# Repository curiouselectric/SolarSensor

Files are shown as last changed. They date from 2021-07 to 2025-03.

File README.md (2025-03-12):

# Solar Sensor
A DIY solar irradiance sensor.

Here are the design files (hardware, PCB and firmware) for a relatively low cost solar irradaince sneesor (called a pyranometer).

[Information relating to the design choices for this unit is available in a blog post here](https://www.re-innovation.co.uk/docs/low-cost-diy-solar-irradiance-sensor-for-pv-system-monitoring/).

This pyranometer is design to measure solar irradiance in Watts per meter squared. This is useful for monitoring systems for solar photovoltaic panels. It can also be used as an indicator value for light levels in many systems.

The main things to note with this design are:

* It does not apply any corrections/filtes for human eye parameters (whcih Lux sensors use, typically for photography or dimming algorithms)
* It does not apply any corrections/filters for plant growing characteristics (typically called PAR  - [Photosynthetically active radiation](https://en.wikipedia.org/wiki/Photosynthetically_active_radiation)

The main issue with this design is the calibration of the sensor data to its actual real-world data. I have attempted to give sensible conversion factors for the sensors used, but calibration for each exact set up with 
calibrated measurement equipment is potentially needed, depending upon you application.

If you are looking for relative changes in irradiance then this sensor is perfectly suitable. 

# Overview
This unit reads irradiance from a photo diode sensor (like a P-N junction in a typical solar photovoltaic cell) every 100mS or so. 

The sensor uses an accurate 16 bit Analog to Digital converter (ADC) (rather than the 10 bit resolution on-board the micrcontorller). This allows for much finer montitoring of the very small current from the solar sensor. As the sensor will 'max out' well below typicaly outdoor irradiance levels, then we use a 6mm PTFE diffuse to attenuate the irradiance signal. This was caclualted from trial and error, but allows up to 2000W/m² to be measured.

There is also a temperature sensor on-board to adjust readings for the sensor temperature. 

It averages those values over different sampling periods of 1, 10, 60 (1 min), 600 (10 min), 3600 (1 hour) seconds. It has an ATMega328 microcontroller onboard for measuring the sensors, processing commands and returnign serial data. A simple serial interface has been implemented (at max 57600 baud) to service requests from another device (such as a data logger or monitoring system). The serial requests can also have CRC for error checking.

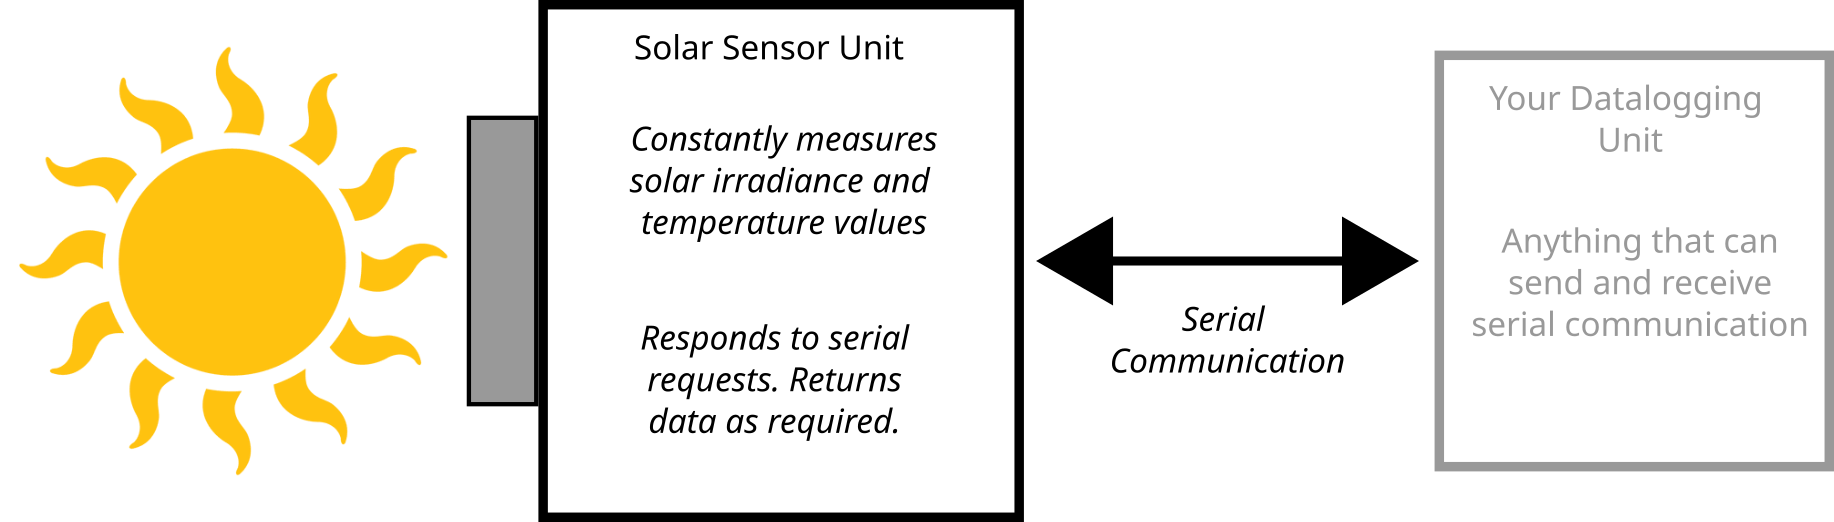
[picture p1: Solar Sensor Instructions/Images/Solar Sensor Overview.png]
Overview


I originally designed this to interface to an ESP32 data logger, which sleeps most of the time. The ESP32 wakes up, gets the data it needs, then goes back to sleep, knowing the solar sensor is always monitoring.

It was designed as a relatively simple interface to remove the need for monitoring irradiance data and averaging it. 
There are other dvices in this range, [including a wind sensor](https://www.curiouselectric.co.uk/collections/environment/products/wind-sensor-interface).

## Irradiance Measurements

The unit stores average irradiance values from the sensor for 1 second, 10 second, 1 min, 10 min and 1 hour values. It also records the maximum and minimum irradiance.

The unit converts the tiny current from the solar PV cell within a photodiode into a "Watts per meter squared" value using a y=mx+c linear conversion, where y is the irradiance value and x is the ADC reading from the photo diode sensor circuitry. m and c are stored in EEPROM and have default values of m=1 and c=0. These are floats and can be changed as required through the serial interface. Any updated values are stored in EEPROM. The output will not go negative - it will round out at 0.

The photodiode used within the prototype is the [SFH203 from OSRAM](https://look.ams-osram.com/m/67e1a90044b03ee9/original/SFH-203.pdf). This has an output repsonse between 400-1100nm with a sensitive area of 1mm² giving a whopping 80uA of photocurrent!

## Temperature Measurements

Temperature near to the board inside the unit is measured using a surface mounted LM75 I2C temperature sensor. This will give an approximate temperature of the sensor. This sensor is accurate to 0.5C. 
Temperature compensation can be applied by updating the config file within the fireware. If the "APPLY_TEMP_COMP" flag is set to "true" then the "TEMP_COMP_VAL" is applied at the real temperature compare to the "RATED_TEMP". Typically the rated temperature is 25C and comes from the [data sheet](https://look.ams-osram.com/m/67e1a90044b03ee9/original/SFH-203.pdf). For the SFH203 the "TEMP_COMP_VAL" is 0.18 %/K and the "RATED_TEMP" is 25C

So an example would be measuring 500 W/m² but the temperature sensor reads 50C.
The rated temperature is 25C, so we need to apply a compensation of (50 - 25) * 0.18 % = 4.5%, so the sensor will be reading 4.5% under the real value (as output is inversly affected by temperature), So the actual irradiance is 500 + (500*0.045) = 522.5 W/m². Not a huge difference, but this might be important.

You can also remove the temperature compensation and record the irradiance and temperature seperately and apply the compensation later.

# Operation

There are two mode of operation, depending upon your use case:

## Response Mode

In this mode then the unit responds to serial requests made. You ask the sensor for data and this is returned. It never sends anything unless asked. 
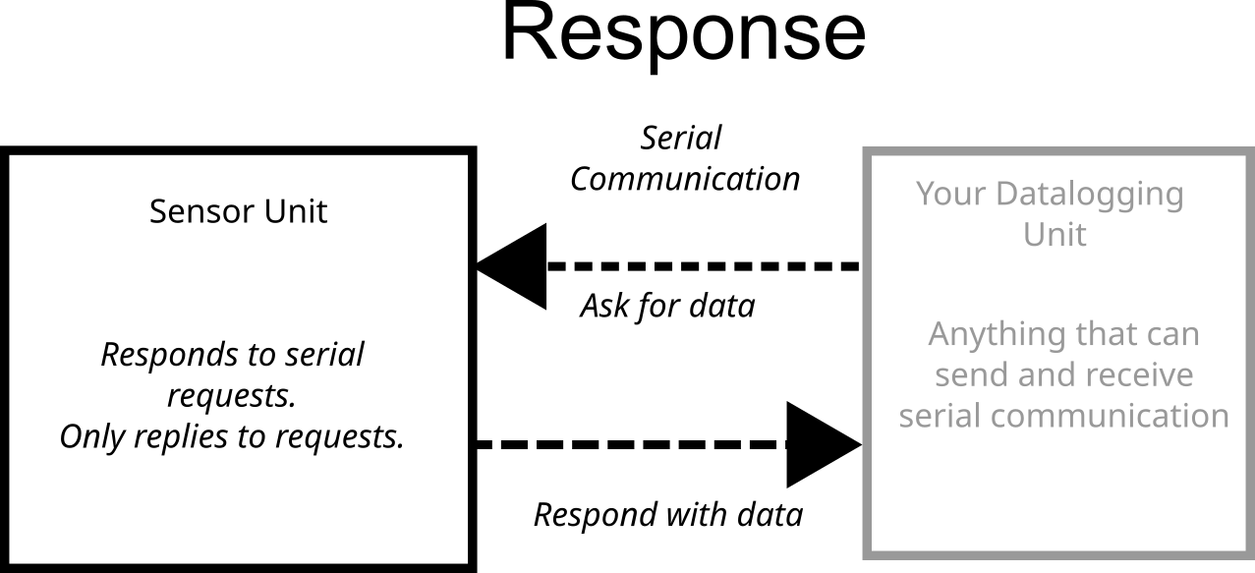
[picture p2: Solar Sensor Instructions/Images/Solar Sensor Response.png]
Response
 

## Broadcast Mode

In this mode then the unit regularly sends data via the serial connunication. It will send the averaged data for (0) 1 second, (1) 10 second, (2) 1 min, (3) 10 min and (4) 1 hour averaged data. If this is set to (5) then the unit does not send any data. The send mdoe is stored in EEPROM, so it will start sending data again even if power is lost.
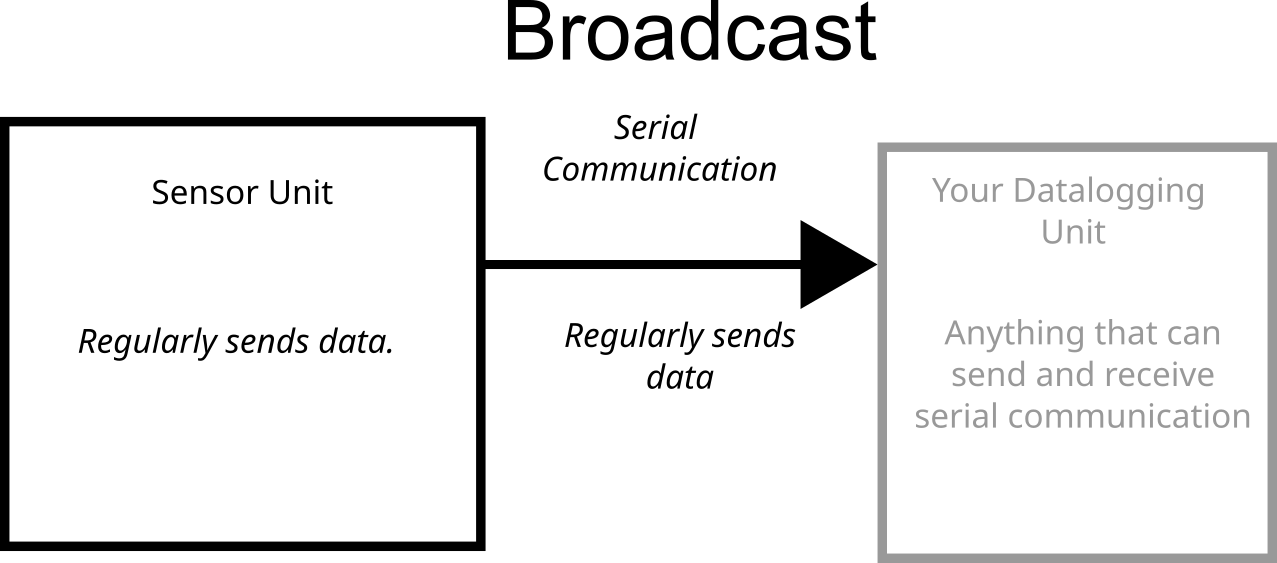
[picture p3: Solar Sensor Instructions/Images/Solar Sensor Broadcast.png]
Broadcast

Boradcast mode works well if the logger is always listening and you only have one sensor in range. If more than one sensor is in range then the data will clash and potentially cause issues, in which case use Response mode.

The two modes work together - you can have the unit sending regular data and also responding to requests.

It runs on an ATMega328 running at 8MHz with selectable baud serial (up to 57600). It comes pre-programmed, but code can be uploaded via the Arduino IDE, using the MiniCore board add-on. See firmware for more details.

# Hardware

The PCB was designed in KiCAD and is available here. A small PCB has been designed.
There is one reset switch, one user input switch and one LED output.

## Board ID Number

Each unit can have a unique ID (using a solder pad for 0-7 values), so multiple units can be added to a serial bus, if needed. The defalt is 0.

## PCB User Switch and User LED

There is one user switch and one user LED on the unit.

The LED will show a regular flash every 5 seconds. This will briefly flash once every 5 seconds if the unit is in 'Response' mode. The LED will briefyl flash twice every 5 seconds if the unit is in 'Broadcast' mode. Data will be sent at the broadcast rate.

The LED will also flash whenever data is sent of the serial port. The LED will go on before data sent and then off after data is sent.

Pressing the user switch for >0.5 seconds and then releasing will result in a switch press. 

A switch press will increment the "mode" from 0-1-2-3-4-5 then back to 0. 

The unit will flash after a button press to indicate the broadcast mode (so 0 flashes if the value is 0, 1 flash if the value is 1 etc). 

If this is set to 5 then the unit works in 'Response' mode. 

If this is set to 0-4 then the unit is in 'Broadcast' mode and will send the data at the relevant interval (0 = 1s, 1 = 10s, 2 = 1 min, 3 = 10 min and 4 = 1 hour). 

The mode can also be set with a serial request, using the "Set the unit to broadcast:" method (see below).

# Firmware
This uses an ATMega328 running at 8MHz with 3.3v or 5V supply.

## Initial bootloader installation:
You should not need to do this, as the unit should come with this already installed. This is just for information.

To upload a bootloader it then MiniCore is used:

Install MiniCore from here: https://github.com/MCUdude/MiniCore

Install the bootloader using an Arduino as an ISP. https://www.arduino.cc/en/Tutorial/BuiltInExamples/ArduinoISP

Wire up your arduino and an ISP 3x2 header pin onto the wind sensor PCB.

Choose the "ATMega328" option with the "External 8MHz Oscillator" set.

You can then use the 'Burn Bootloader' option within 'Tools' in the Arduino IDE. This will install the Minicore bootloader.

## Program via Arduino IDE

To program it then MiniCore is used:

Install MiniCore from here: https://github.com/MCUdude/MiniCore

Add to preferences and then board manager.

You can then upload code by choosing the "ATMega328" option with the "External 8MHz Oscillator" set.

# Serial Data and Commands

It returns the average values and information when requested on serial port.

At all other times then the unit is asleep.

This unit is called the Solar Sensor, so I used "SS" as its simple serial name.

## Irradiance data:
REQUEST: “aaI0SSA4#”  ("aaI0SSA4?41#" with CRC)  Where 0 is an ID from 0-7 set by solder on PCB. 4 is the averaging period (0=1s, 1=10s, 2 = 60s, 3 = 600s, 4=3600s)  

RETURNED: "aaI0SSA1:28.5:28.6:28.5:18.0#" 

where the first number (between semi-colons) is the average, 2nd number is the Maximum (until a reset is done), 3rd number is the Minimum and 4th number is the temperature.

Temperature has a resolution of 0.5 C (18.0C in this example).

Response will include the averaging number (1 in this example).
                                      
## Irradiance data minimum:

REQUEST: “aaI0SSMN#” ("aaI0SSMN?dc#" with CRC) - does not matter what averaging period. min/max are just the min/max seen.

RETURNED: "aaI0SSMN:27.9#" where the number after semi-colon is the minimum. (+CRC if requested)
                                      
## Irradiance data maximum:

REQUEST: “aaI0SSMX#”  ("aaI0SSMX?be#" with CRC) - does not matter what averaging period. min/max are just the min/max seen.

RETURNED: "aaI0SSMX:28.9#" where the number after semi-colon is the maximum. (+CRC if requested)

## Reset the min/max:

REQUEST:   “aaI0RESET#” ("aaI0RESET?d9#" with CRC) this will Reset Min & Max.  

RETURNED:  Nothing

This command will reset the min/max. Min and max will be stored until this reset command is issued.

## What is Irradiance Sensor conversion?: 

REQUEST:  "aaI0SSCON#"    Ask for the stored irradiance conversion values

RETURNED: "aaI0SSCONm10.00c0.00#"  With the numbers after m and c being the conversion values (+CRC if requested).
                                      
## Set the Irradiance Sensor conversion:      

REQUEST:  "aaI0SSSETm123.4c567.89#"    SET the stored irradiance conversion values
  
RETURNED: "aaI0SSSETm123.4c567.89#"     With the numbers after m and c being the conversion values

Note: Request: "aaI0SSSETm1c0#" or "aaI0SSSETm1c0?34#" with CRC to set m= 1 and c=0. This is useful for initial testing.

## What is Temperature conversion?: 

REQUEST:  "aaI0SSTCON#"    Ask for the stored conversion values

RETURNED: "aaI0SSTCONp0.18r25.0#"  With the numbers after p being the percentage adjustment and r being the reated temperature (in C) (+CRC if requested).
                                      
## Set the Temperature conversion:      

REQUEST:  "aaI0SSTCONp0.18r25.0#"    SET the stored conversion values
  
RETURNED: "aaI0SSTCONp0.18r25.0#"     With the numbers after m and c being the conversion values

## Switch on/off Temperature conversion: 

REQUEST:  "aaI0SSTCONON#"  to set temperature conversion ON. REQUEST:  "aaI0SSTCONOFF#" to set temperature conversion OFF

RETURNED: "aaI0SSTCONON#" or "aaI0SSTCONOFF#" (+CRC if requested).
                                      
## Set the unit to broadcast:  
REQUEST: "aaI0SEND?#" where ? is an int (0)= 1s data, (1)= 10s data, (2)= 60s/1 min data, (3)= 600s/10 min data, (4)= 3600s/1hr data, (5)= NO data 

RETURNED: "aaI0SENDOK#" + CRC if requested

You can also set the unit to broadcast using the user switch. Press the button for around 0.5s or more then release. This will go through the boradcast modes from 0-1-2-3-4-5 then back round to 0. The LED will flash the number of times for the setting (so send = 0 the unit will not flash, but data will appear within 1 second!).

If the unit is in broadcast mode then the minimum and maximum wind speeds and the wind vane data are all reset each time period.

## What is baud rate?:                 
REQUEST: "aaI0BD#" ("aaI0BD?dc#" with CRC for device ID 0 or "aaI1BD?b7#" for device ID 1)

RETURNED: "aaBD9600#"  // Where 9600 is the baud rate + CRC if requested
                                      
## Set Baud Rate:                      
REQUEST: "aaI0STBD*#"  Where * is (0)1200, (1)2400, (2)9600, (3)57600, (4)115200

RETURNED: "aaBD9600#"   // Where 9600 is the baud rate + CRC if requested

## What is ID?:                        
Mentioned at start up of unit - it is solder-programmed... cannot be changed in code.

ID selection is by using a blob of solder to connect together some pads labelled A0, A1 and A2. The default is for no pads to be soldered and the ID is 0. This means the unit will respond to "I0" as the ID.

To change the ID to another number from 0-7 then we can solder the different connection pads to create a binay number. The connections are:

A0     |A1     |A2     | ID
-------|-------|-------|----
NC     |NC     |NC     | 0
Solder |NC     |NC     | 1
NC     |Solder |NC     | 2
Solder |Solder |NC     | 3
NC     |NC     |Solder | 4
Solder |NC     |Solder | 5
NC     |Solder |Solder | 6
Solder |Solder |Solder | 7

## Serial 'Button' press

The command "aaI0BUTTON" + CRC + "#" will act just like a button press. This is for control via a data logger serial port without access to the physical switch.
e.g. This is "aaI1BUTTON?f4#" including CRC for device ID 1.

## Add CRC check:           
Within the config of the firmware a CRC (Cyclic Redundancy Check) can be added to the data (or not!).

Set this true using the flag in the config.h file:

  #define ADD_CRC_CHECK     true    // Use this to add CRC check to incomming and outgoing messages

This uses the CRC routines from Rob Tillaart, available here: https://github.com/RobTillaart/CRC

A 'crc8' is perfromed on the data and a 2 byte CRC code is added to all replys (and expected on all enquiries). This is added between a ? and # symbol.

If no CRC then the end char is a #.

For example: aaI0RESET?d9# has the CRC check d9 added to the reset request.

Remember: Capitalisation will affect the results: D is not the same as d!

You can use this online calculator to check your CRC: https://crccalc.com/ 

**The type of CRC is CRC-8/SMBUS.**

## Failure codes:

If data is not that length or does not have 'aa' and '#' at start/end then return with send "aaFAIL**#" error code. All will have CRC on these codes, if requested.

## Analog Output

There is an analog output on the device which will always output a voltage which is proportional to the irradiance level. This is useful if you just want to see the data on a multimeter or some panel meter.

The unit is set with a maxinmum irradiance of 2000W/m². This will give the maximum output from the analog output (which will be Vcc (the supply voltage)). At an irradiance of 1000W/m² then the output will be Vcc/2.

This means we need a relatively stable and accurate power supply to give stable and accurate output.

Note: 
* Only have 256 levels for the analog output.
* Need to know Vcc to get absolute value
* Can output up to MAX_IRRADIANCE W/m2 MAX, which is set in the firmware to 2000W/m²
  
Example: So 1000 W/m2 = 256*1000/MAX_IRRADIANCE = PWM Value 128 => Vcc/ 2 (for MAX_IRRADIANCE = 2000 W/m2)
  
Example: So 100 W/m2 = 256*100/MAX_IRRADIANCE = PWM Value 12.8 (or 13 in discrete levels) => Vcc/20 (for MAX_IRRADIANCE = 2000 W/m2)

The resolution of the output is Vcc/256, so for 5V Vcc this is  0.01953V or 19.5mV

A reading of 1000W would be PWM of 128 which gives output of 2.5V

A reading of 100W would should give PWM of 12.8 (so output voltage should be 0.25V) BUT 12.8 is converted to 13 as an INT (rounding up)

So output is actually 0.2539V. Basically there is a 'step' of 19.5mV (at Vcc = 5V) so data will be 'stepped'

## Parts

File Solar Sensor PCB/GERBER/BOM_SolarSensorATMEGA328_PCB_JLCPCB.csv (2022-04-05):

Comment | Designator | Footprint | LCSC
10n | C1 | REInnovationFootprint:SM_C_0805 | C107135
22p | C9,C10 | REInnovationFootprint:SM_C_0805 | C1804
100n | C2,C3,C4,C5,C7,C8,C11 | REInnovationFootprint:SM_C_0805 | C49678
100u | C6 | REInnovationFootprint:SM_6.3x7.7 | C164071
PHOTO DIODE | D1 | REInnovationFootprint:LED-5MM_PHOTODIODE
OUT | D2 | REInnovationFootprint:SM0805_LED | C2296
ANALOG | J1 | REInnovationFootprint:SIL-3_screw_terminal
I2C | P1,P10 | REInnovationFootprint:SIL-4_Grove_Not_Labelled
SERIAL | P2 | REInnovationFootprint:SIL-4_Grove_SCREW
ID | P3 | REInnovationFootprint:SM_6pad_3W_SOLDER
ISP | P4 | REInnovationFootprint:ISP_3x2
LOGO2 | P5 | CuriousElectric3:TCEC_Words_13mm
PCB | P6 | REInnovationFootprint:PCB_SolarSensorATMEGA328_PCB_design_v2
ENC | P7
ADC | P8 | REInnovationFootprint:SIL-4_large_pad
PROG | P9 | REInnovationFootprint:TH_6x1_FTDI
47k | R1 | REInnovationFootprint:SM0805 | C17713
10k | R2,R5 | REInnovationFootprint:SM0805 | C17414
470 | R4 | REInnovationFootprint:SM0805 | C17710
4k7 | R6,R7 | REInnovationFootprint:SM0805 | C17673
SWA | SW1 | REInnovationFootprint:SMD_SW_6x3_5 | C412368
RST | SW2 | REInnovationFootprint:SMD_SW_6x3_5 | C412368
TSV911xxLx | U1 | REInnovationFootprint:SM_SOT-23-5 | C361052
MCP3426-xSN | U2 | REInnovationFootprint:SM_SOIC_8
LM75B | U3 | REInnovationFootprint:SM_SOIC_8 | C34565
ATmega328P-AU | U4 | REInnovationFootprint:TQFP32-08 | C14877
8MHz_XTAL | Y1 | REInnovationFootprint:SM-crystal-HC49UP | C12674

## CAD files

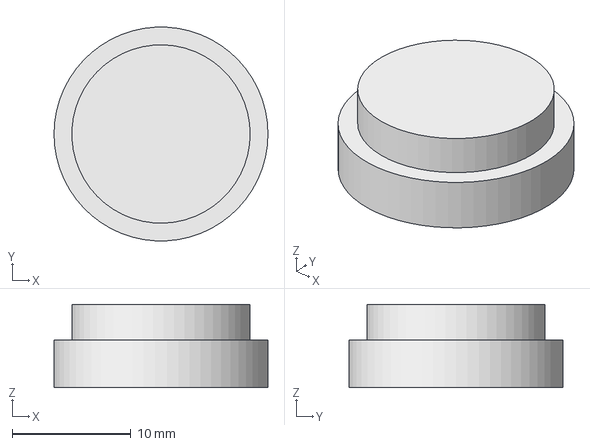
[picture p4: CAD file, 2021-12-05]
Solar Sensor Hardware/Diffuser Design/Diffuser_Stepped_design_v5_7mm_PTFE.FCStd
18.0 x 18.0 x 7.00 mm

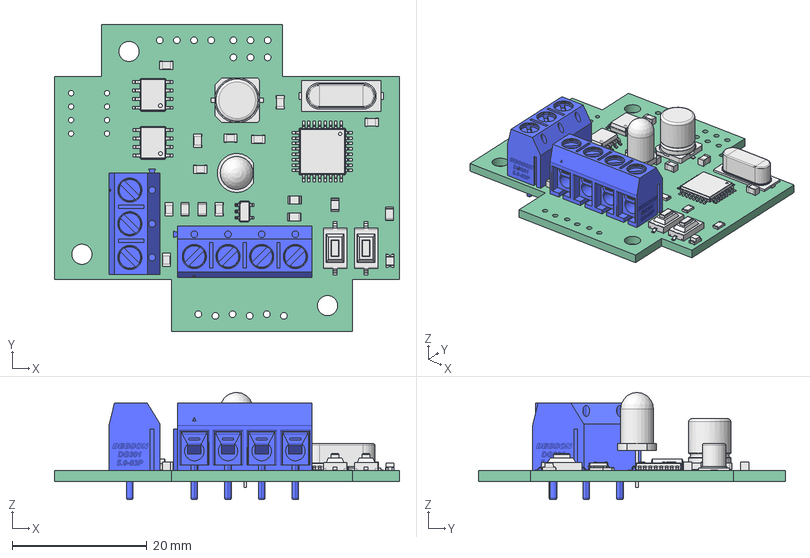
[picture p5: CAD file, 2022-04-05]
Solar Sensor Hardware/PCB 3D Model/SolarSensorATMEGA328_PCB_freeCAD.FCStd
51.2 x 45.6 x 15.9 mm
Pcb_ab9b
SW2_SW_SPST_CK_RS282G05A3_60F30811 x 2
D2_LED_0805_2012Metric_Castellated_60F53ACF
R7_R_0805_2012Metric_60F30805 x 6
C7_C_0805_2012Metric_60F30728[2] x 10
U4_TQFP_32_7x7mm_P08mm_60F30876
P2_DG301-5.0-04P-12-00AH_60F301A6
U1_TSOP_5_165x305mm_P095mm_60F30822
Y1_Crystal_SMD_HC49-SD_60F3089C
C6_C_Elec_63x77_60F3729F
U3_SOIC_8_1EP_39x49mm_P127mm_60F308EF x 2
J1_DG301-5.0-03P-12-00AH_61BC8E52
D1_LED_D5.0mm_Clear_61C65468

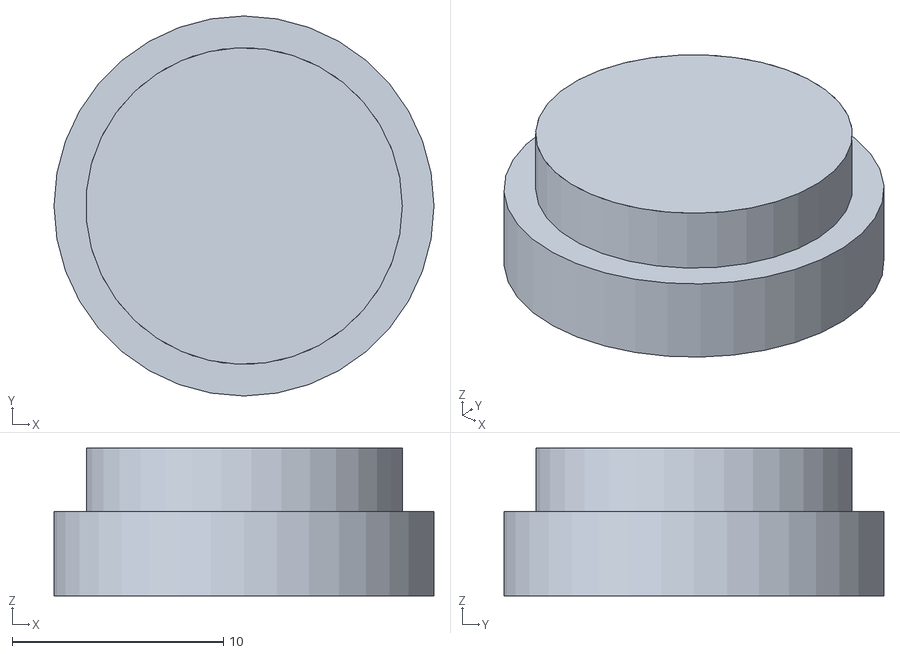
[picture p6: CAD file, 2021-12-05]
Solar Sensor Hardware/Diffuser Design/Diffuser_Stepped_design_v5_7mm_PTFE-Fusion.stl
18.0 x 18.0 x 7.00

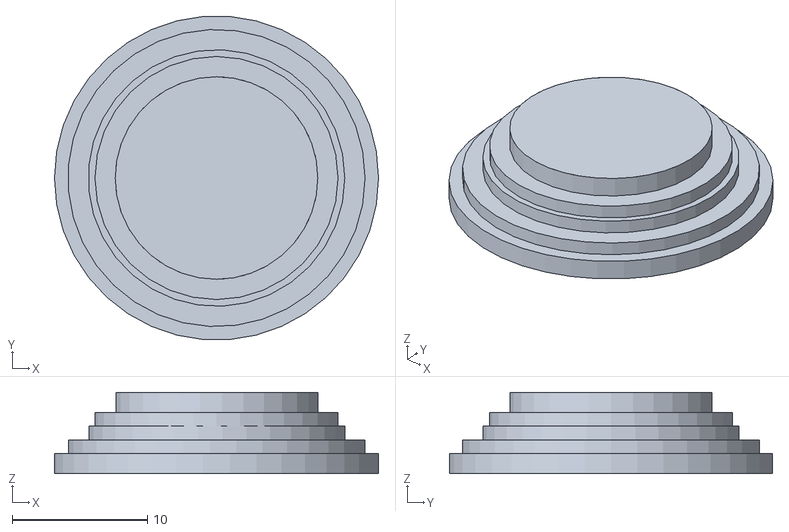
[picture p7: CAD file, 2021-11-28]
Solar Sensor Hardware/Diffuser Design/Diffuser_Stepped_design_v2_6mm_PTFE-Fusion.stl
24.0 x 23.9 x 6.00

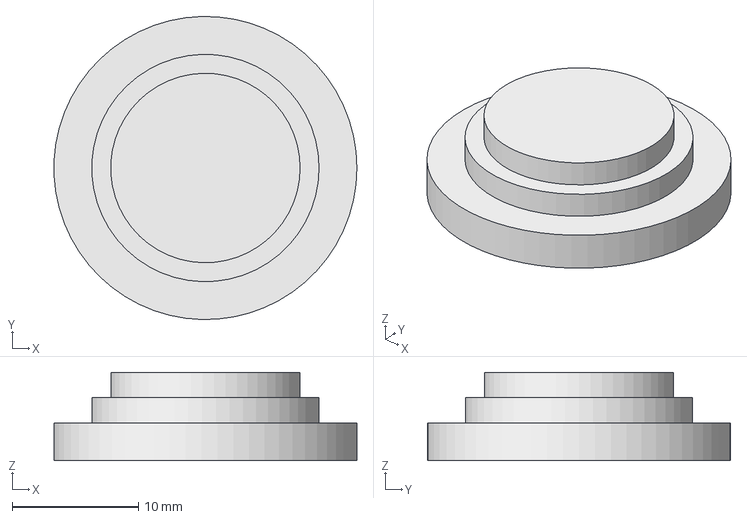
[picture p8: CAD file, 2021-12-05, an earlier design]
Solar Sensor Hardware/Diffuser Design/OLD/Diffuser_Stepped_design_v4_7mm_PTFE.FCStd
24.0 x 24.0 x 7.00 mm

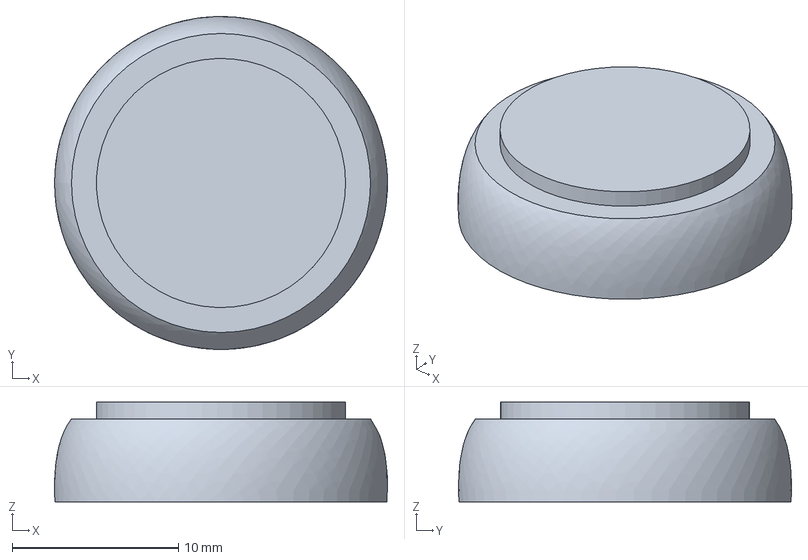
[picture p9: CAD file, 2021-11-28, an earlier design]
Solar Sensor Hardware/Diffuser Design/OLD/Diffuser_design_6mm_PTFE.FCStd
20.0 x 20.1 x 6.00 mm

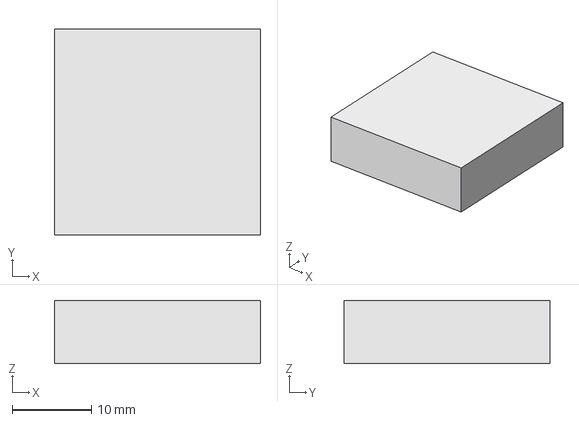
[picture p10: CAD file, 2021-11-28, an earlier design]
Solar Sensor Hardware/Diffuser Design/OLD/Diffuser_Stepped_design_6mm_PTFE.FCStd
26.0 x 26.0 x 8.00 mm

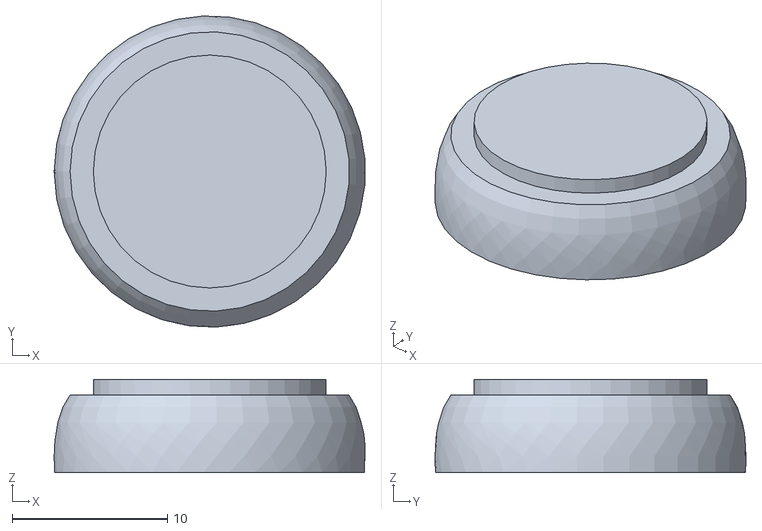
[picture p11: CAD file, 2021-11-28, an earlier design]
Solar Sensor Hardware/Diffuser Design/OLD/Diffuser_design_6mm_PTFE_3D.stl
20.0 x 20.0 x 6.00

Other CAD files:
Solar Sensor Hardware/Diffuser Design/Diffuser_Stepped_design_v2_6mm_PTFE.FCStd
Solar Sensor Hardware/Diffuser Design/OLD/Diffuser_Stepped_design_v4_7mm_PTFE-Fusion.stl
Solar Sensor Hardware/Diffuser Design/OLD/Diffuser_Stepped_design_v3_6mm_PTFE.FCStd
Solar Sensor Hardware/Diffuser Design/OLD/Diffuser_Stepped_design_v3_6mm_PTFE-Fusion.stl
Solar Sensor Hardware/Diffuser Design/OLD/Diffuser_design_6mm_PTFE_2.FCStd
Solar Sensor Hardware/Diffuser Design/OLD/Diffuser_Stepped_design_v2_6mm_PTFE.FCStd
Solar Sensor Hardware/Diffuser Design/OLD/Diffuser_design_6mm_PTFE_2-Fusion.stl
Solar Sensor Hardware/Diffuser Design/OLD/Diffuser_design_6mm_PTFE.stl

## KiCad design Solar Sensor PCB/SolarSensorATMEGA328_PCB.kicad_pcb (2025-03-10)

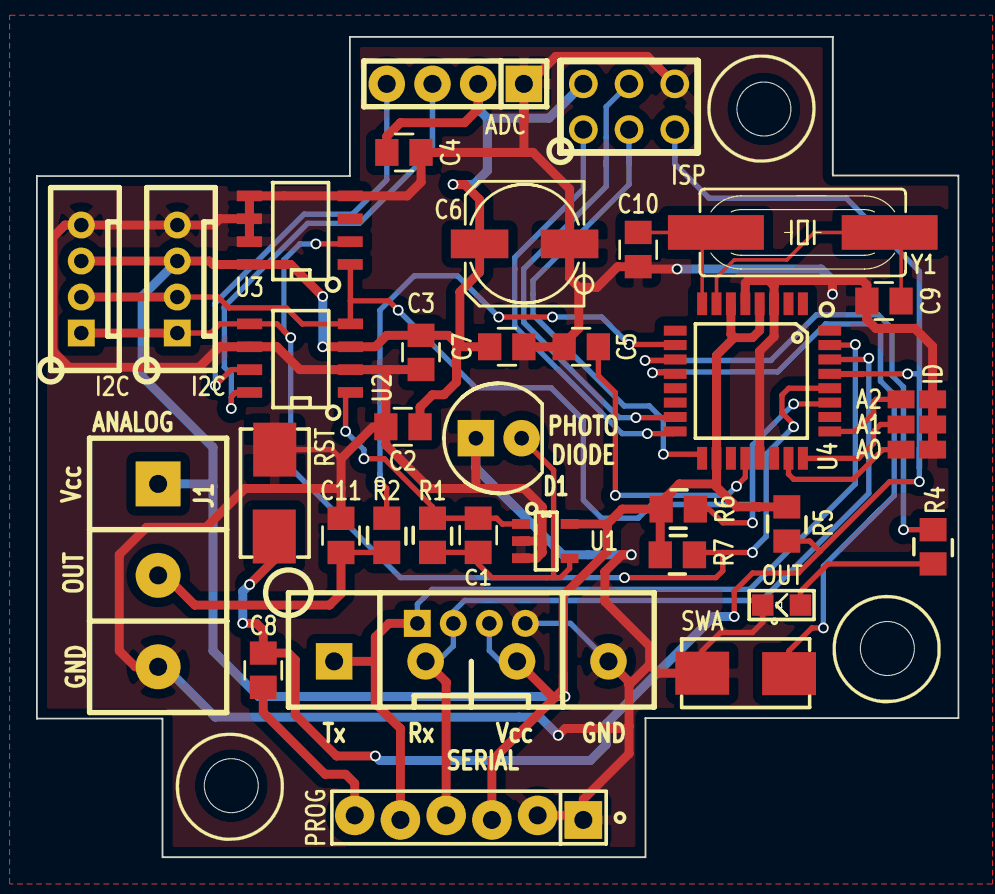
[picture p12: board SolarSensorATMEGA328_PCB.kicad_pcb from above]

Board: 2 copper layers, 51.2 x 45.6 mm, 36 parts (1 on the bottom side), 26 nets.

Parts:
C1: 10n; SM_C_0805
C2, C3, C4, C5, C7, C8, C11: 100n; SM_C_0805
C6: 100u; SM_6.3x7.7
C9, C10: 22p; SM_C_0805
D1: PHOTO DIODE; LED-5MM_PHOTODIODE
D2: OUT; SM0805_LED
J1: ANALOG; SIL-3_screw_terminal
P1, P10: I2C; SIL-4_Grove_Not_Labelled
P2: SERIAL; SIL-4_Grove_SCREW
P3: ID; SM_6pad_3W_SOLDER
P4: ISP; ISP_3x2
P5: LOGO2; TCEC_Words_13mm
P6: PCB; PCB_SolarSensorATMEGA328_PCB_design_v2
P8: ADC; SIL-4_large_pad
P9: PROG; TH_6x1_FTDI
R1: 47k; SM0805
R2, R5: 10k; SM0805
R4: 470; SM0805
R6, R7: 4k7; SM0805
SW1: SWA; SMD_SW_6x3_5
SW2: RST; SMD_SW_6x3_5
U1: TSV911xxLx; SM_SOT-23-5
U2: MCP3426-xSN; SM_SOIC_8
U3: LM75B; SM_SOIC_8
U4: ATmega328P-AU; TQFP32-08
Y1: 8MHz_XTAL; SM-crystal-HC49UP

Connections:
/ATMega328/A0: P3.5, U4.23
/ATMega328/A1: P3.3, U4.24
/ATMega328/A2: P3.1, U4.25
/ATMega328/D6: R2.1, U4.10
/ATMega328/D7_LED0: R4.1, U4.11
/ATMega328/D8_SWA: SW1.1, U4.12
/ATMega328/DTR: C8.1, P9.6
/ATMega328/MISO: P4.1, U4.16
/ATMega328/MOSI: P4.4, U4.15
/ATMega328/RESET: C8.2, P4.5, R5.2, SW2.1, U4.29
/ATMega328/SCLK: P4.3, U4.17
/I2C_CLK: P1.1, P10.1, R7.2, U2.5, U3.2, U4.28
/I2C_SDA: P1.2, P10.2, R6.2, U2.4, U3.1, U4.27
/IRR_A: C11.1, J1.2, R2.2
/Rx: P2.2, P9.4, U4.30
/Tx: P2.1, P9.5, U4.31
GND: C2.1, C3.2, C4.1, C5.1, C6.2, C7.1, C9.1, C10.1, C11.2, D1.1, D2.1, J1.3, P1.4, P2.4, P3.2, P3.4, P3.6, P4.6, P8.1, P9.1, P9.2, P10.4, SW1.2, SW2.2, U1.2, U1.3, U2.2, U2.6, U3.4, U3.5, U3.6, U3.7, U4.3, U4.5, U4.21
unnamed: C1.1, R1.1, U1.1, U2.1
unnamed: C1.2, D1.2, R1.2, U1.4
unnamed: C5.2, U4.20
unnamed: C9.2, U4.7, Y1.1
unnamed: C10.2, U4.8, Y1.2
unnamed: D2.2, R4.2
unnamed: P8.3, U2.8
unnamed: P8.4, U2.7
VCC: C2.2, C3.1, C4.2, C6.1, C7.2, J1.1, P1.3, P2.3, P4.2, P8.2, P9.3, P10.3, R5.1, R6.1, R7.1, U1.5, U2.3, U3.8, U4.4, U4.6, U4.18

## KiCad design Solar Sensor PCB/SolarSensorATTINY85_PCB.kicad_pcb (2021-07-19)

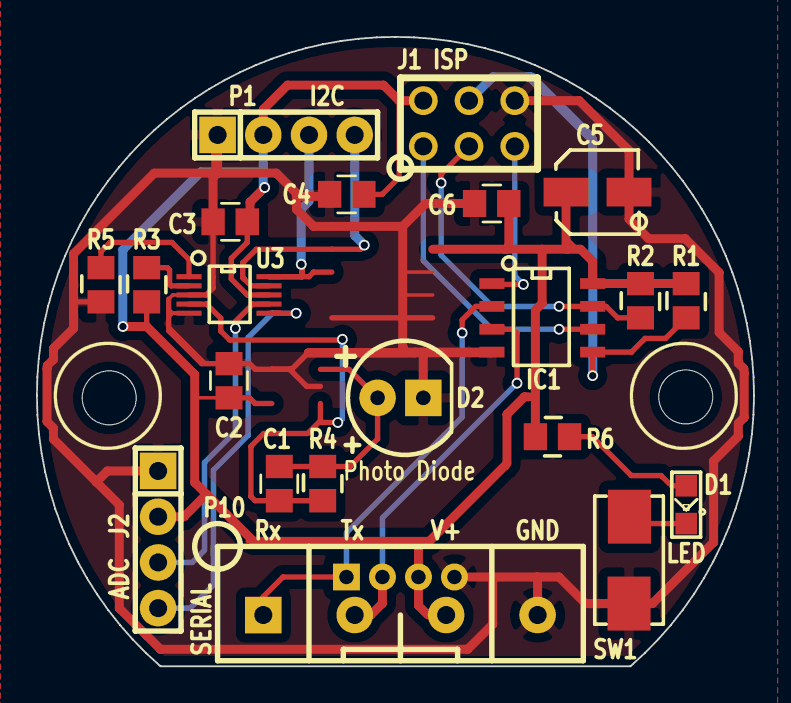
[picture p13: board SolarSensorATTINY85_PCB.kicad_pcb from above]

Board: 2 copper layers, 39.8 x 35.0 mm, 23 parts (1 on the bottom side), 18 nets.

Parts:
C1: 10n; SM_C_0805
C2, C3, C4, C6: 100n; SM_C_0805
C5: 100u; SM_4x5.3
D1: LED; SM0805_LED
D2: PHOTO DIODE; TH_LED-5MM_larg_pad
IC1: ATTINY85-P; SM_SOIC_8
J1: ISP; ISP_3x2
J2: ADC; SIL-4_large_pad
P1: I2C; SIL-4_large_pad
P5: LOGO2; TCEC_Words_13mm
P6: PCB; PCB_40mm_Round_SolarSensorPCB_design
P10: SERIAL; SIL-4_Grove_SCREW
R1, R2, R3, R5: 10k; SM0805
R4: 47k; SM0805
R6: 330R; SM0805
SW1: UP; SMD_SW_6x3_5
U3: ADS1115; SM_MSOP10-0.5

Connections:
+5V: C2.2, C3.1, C4.2, C5.1, C6.1, IC1.8, J1.2, J2.2, P1.2, P10.3, R1.1, R2.1, R3.1, R6.1, U3.8
/D0: IC1.5, J1.4, R1.2
/D1: IC1.6, J1.1
/D2: IC1.7, J1.3, R2.2
/D3: IC1.2, P10.1
/D4: IC1.3, P10.2
/SCL_I2C: P1.3, U3.10
/SDA_I2C: P1.4, U3.9
/SW1: D1.1, SW1.1
GND: C2.1, C3.2, C4.1, C5.2, C6.2, D2.2, IC1.4, J1.6, J2.1, P1.1, P10.4, R5.1, SW1.2, U3.3, U3.5
unnamed: C1.1, R4.1, U3.4
unnamed: C1.2, D2.1, R4.2
unnamed: D1.2, R6.2
unnamed: IC1.1, J1.5
unnamed: J2.3, U3.7
unnamed: J2.4, U3.6
unnamed: R3.2, U3.2
unnamed: R5.2, U3.1

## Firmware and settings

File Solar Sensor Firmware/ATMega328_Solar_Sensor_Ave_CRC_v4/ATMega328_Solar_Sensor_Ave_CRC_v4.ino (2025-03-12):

/*
   Solar Sensor Averaging firmware for ATMega328
   by:    Matt Little
   date:  27/10/2021
   w:     www.curiouselectric.co.uk
   e:     hello@curiouselectric.co.uk

   This code is for an ATMega328 unit solar sensor unit.
   This uses an ATMega328 running at 8MHz with 3.3v or 5V supply.

   It returns the average values when requested on serial port.
   Or it broadcasts solar speed and direction data at set intervals.
   At all other times then the unit is asleep.

   Serial commands you can use:

   REQUEST: Get data:    “aaI0SSA?#” where ? is the averaging number from 0-4.
   Averaging number: 0 = 1 second, 1 = 10 second, 2 = 60 second, 3 = 600 second (10 min), 4 = 3600 second (1hr)
   RETURNED: "aaI0SSA1:28.51:28.60:28.50:18.00#"
   where the first number (between semi-colons) is the average, 2nd number is the Maximum (until a reset is done),
   3rd number is the Minimum and 4th number is the temperature.
   Temperature has a resolution of 0.5 C.
   Response will include the averaging number.

   REQUEST: Get Maximum:    “aaI0SSMX#”
   RETURNED: "aaI0SSMX:28.90#" where the number after semi-colon is the maximum

   REQUEST: Get Miniimum:    “aaI0SSMN#”
   RETURNED: "aaI0SSMN:27.90#" where the number after semi-colon is the minimum

   REQUEST: Reset Min & Max:    “aaI0RESET#”
   RETURNED: Nothing
   This will reset the maximum and minimum values

   REQUEST:   What is baud rate?:  "aaI0BD#"
   RETURNED:  "aaI0BD9600#" Where the number between D and # is the baud rate.
   This is stored in EEPROM so will stay the same even on power down.

   REQUEST:  Set Baud Rate:   "aaI0STBD*#"  Where * is 0,1,2,3,4 for 1200, 2400, 9600, 57600, 115200
   RETURNED: "aaI0STBD9600#"  Where the number between D and # is the baud rate.

   REQUEST: What is ID?:   "aaI?#"      Mentioned at start up of unit as well - its solder-programmed... cannot be changed in code.
   RETURNED: "aaIx#" where x is the ID (from the soldered ID pads. Default is 0);
   The ID can be set using the soldered pads from 0-7.
   The default (no pads soldered) is an ID of 0.
   Other combinations are (X = not soldered, = = soldered):
   A0     A1    A2    ID
   X      X     X     0
   =      X     X     1
   X      =     X     2
   =      =     X     3
   X      X     =     4
   =      X     =     5
   X      =     =     6
   =      =     =     7

  Data conversion:
  The unit has a linear y=mx+c type conversion applied to the solar data (to scale and offset).
  So the output value (y) will be the voltage read (x) multiplied by m and then adding c
  The values for m and c are stored in EEPROM
  They can be requested and adjusted as stated here:

  REQUEST:  "aaI0SSCON#"    Ask for the stored conversion values
  RETURNED: "aaI0SSCONm10.00c0.00#"  With the numbers after m and c being the conversion values

  REQUEST:  "aaI0SSSETm123.4c567.89#"    SET the stored conversion values
  RETURNED: "aaI0SSSETm123.4c567.89#"     With the numbers after m and c being the conversion values

  Send data for checking/display:

  REQUEST:  "aaI0SEND?#" where ? is the averaging number from 0-5.
  Averaging number: 0 = 1 second, 1 = 10 second, 2 = 60 second,
  3 = 600 second (10 min), 4 = 3600 second (1hr), 5 = STOP send
  RETURNED: "aaI0SENDON#" or "aaI0SENDOFF#
  Then at regular intervals
  RETURNED: "aaI0SSA?:9.00:9.00:9.00:19.00#"  Data will be returned at the averaging period.

  If you press the SWA button for about 0.5-1 second then the unit will also enter SEND data mode.
  It will cycle through the send averaging numbers from 0 = 1 second, 1 = 10 second, 2 = 60 second,
  3 = 600 second (10 min), 4 = 3600 second (1hr), 5 = STOP send
  This will loop back around. 0 -> 5 -> 0
  The LED will flash 1 time for 0, 2 for 1, 3 for 2, 4 for 3 and 5 for 4 (I know!) and then one long led light for OFF.

  Pressing and holding the button for > 3 seconds will set the unit directly into OFF

   Temperature Compensation:

   The output from the photo diode will depend upon temperature.
   Need to know the temperature variation from the photo diode datasheet
   Using a: SFH203 T1 3/4 PHOTODIODE (UNFILTERED) RC
   Datasheet here: https://www.osram.com/ecat/Radial%20T1%203-4%20SFH%20203/com/en/class_pim_web_catalog_103489/prd_pim_device_2219554/
   This comes from the light sensor datasheet. I have settled on the SFH-203 from OSRAM. This is rated at 25C and has coefficients for voltage and short circuit current.
   We are using the short circuit current which is measured by the op-amp.
   The temperature coefficient of the short circuit current is 0.18 % / K.
   So to compensate the reading for temperature we need to adjust up/down depending upon the temperature.
   The adjustment is: Adjustment = (LM75B temperature - 25) * 0.18 %
   We then need to apply this factor to our irradiance value: Real irradiance = Measured Value - Measured Value * (Adjustment / 100)

   There is the "APPLY_TEMP_COMP" flag in the config to say if this is applied or not.


  Analog Output

  Only have 256 levels for the analog output.
  Need to know Vcc to get absolute value
  This gives headroom for > 1000W/m2
  Can output up to MAX_IRRADIANCE W/m2 MAX

  Example: So 1000 W/m2 = 256*1000/MAX_IRRADIANCE = PWM Value 128 => Vcc/ 2 (for MAX_IRRADIANCE = 2000 W/m2)

  Example: So 100 W/m2 = 256*100/MAX_IRRADIANCE = PWM Value 12.8 (or 13 in discrete levels) => Vcc/20 (for MAX_IRRADIANCE = 2000 W/m2)

  solar_data.data_1s is the float value in W/m2
  So PWM value is:
  PWM_float = ( 256.0 * solar_data.data_1s ) / (float)MAX_IRRADIANCE;
  Then convert to an INT -> analogWrite(ANALOG_OUT_PIN, PWM_float);

  The resolution of the output is Vcc/256, so for 5V Vcc this is  0.01953V or 19.5mV
  A reading of 1000W would be PWM of 128 which gives output of 2.5V
  A reading of 100W would should give PWM of 12.8 (so output voltage should be 0.25V) BUT 12.8 is converted to 13 as an INT (rounding up)
  So output is actually 0.2539V. Basically there is a 'step' of 19.5mV (at Vcc = 5V) so data will be 'stepped'


   Details on the design of this device are here:
   https://www.re-innovation.co.uk/docs/low-cost-diy-solar-irradiance-sensor-for-pv-system-monitoring/

   Please see the github rpository readme for all the serial commands available.
   https://github.com/curiouselectric/SolarSensor

   To program it then MiniCore is used:
   // For optiboot using 3.3V and 8MHz and with WDT we need to sort out new code:
   Easiest method is:
   Install MiniCore from here: https://github.com/MCUdude/MiniCore
   Add https://mcudude.github.io/MiniCore/package_MCUdude_MiniCore_index.json to preferences and then board manager.

   Use minicore to burn the bootloader with an Arduino as an ISP using the 'Burn Bootloader' option

*/

#include <stdio.h>
#include <Arduino.h>
#include <Wire.h>
#include <EEPROM.h>       // for saving mode to EEPROM
#include <avr/wdt.h>      // for the watch dog timer

// For the LM75 I2C temperature sensor:
// https://github.com/jeremycole/Temperature_LM75_Derived
#include <Temperature_LM75_Derived.h>

//For the MCP3426 ADC I2C sensor:
// https://github.com/stevemarple/MCP342x
#include <MCP342x.h>


#include "Button2.h"      // Need to include this to the library
#include "config.h"
#include "serial_parse.h"
#include "solar_data.h"
#include "crc_check.h"

#include "utilitiesDL.h"
// 0x68 is the default address for all MCP342x devices
MCP342x adc = MCP342x(MCP_ADDRESS);

// The Generic_LM75 class will provide 9-bit (±0.5°C) temperature for any
// LM75-derived sensor. More specific classes may provide better resolution.
Generic_LM75 temperature(0x48);

// ****** This is for the buttons button2 library used and needs to be installed ********
// https://github.com/LennartHennigs/Button2
Button2 buttonA = Button2(SWA_PIN);

int SERIAL_BAUD;
long int baud_rates[MAX_BAUD_RATES] = {1200, 4800, 9600, 57600, 115200}; // This holds the available baud rates

// ******** This is for Scheduling Tasks **************************
// Must include this library from Arduino IDE Library Manager
// https://github.com/arkhipenko/TaskScheduler
#include <TaskScheduler.h>

// #define _TASK_TIMECRITICAL      // Enable monitoring scheduling overruns
#define _TASK_SLEEP_ON_IDLE_RUN    // Enable 1 ms SLEEP_IDLE powerdowns between tasks if no callback methods were invoked during the pass
// #define _TASK_STATUS_REQUEST    // Compile with support for StatusRequest functionality - triggering tasks on status change events in addition to time only
// #define _TASK_WDT_IDS           // Compile with support for wdt control points and task ids
// #define _TASK_LTS_POINTER       // Compile with support for local task storage pointer
// #define _TASK_PRIORITY          // Support for layered scheduling priority
// #define _TASK_MICRO_RES         // Support for microsecond resolution
// #define _TASK_STD_FUNCTION      // Support for std::function (ESP8266 and ESP32 ONLY)
// #define _TASK_DEBUG             // Make all methods and variables public for debug purposes
// #define _TASK_INLINE            // Make all methods "inline" - needed to support some multi-tab, multi-file implementations
// #define _TASK_TIMEOUT           // Support for overall task timeout
// #define _TASK_OO_CALLBACKS      // Support for dynamic callback method binding
// #define _TASK_DEFINE_MILLIS     // Force forward declaration of millis() and micros() "C" style
// #define _TASK_EXPOSE_CHAIN      // Methods to access tasks in the task chain

// Callback methods prototypes
void t1Callback();
void t1SCallback();
void t10SCallback();
void t60SCallback();
void t600SCallback();
void t3600SCallback();

// Tasks
// time (mS) between tasks, number of tasks to do, call back function
/*
  Scheduling defines:
  TASK_MILLISECOND
  TASK_SECOND
  TASK_MINUTE
  TASK_HOUR
  TASK_IMMEDIATE
  TASK_FOREVER
  TASK_ONCE
  TASK_NOTIMEOUT
*/

Task t1     (100 * TASK_MILLISECOND, TASK_FOREVER,  &t1Callback);   // Sample as base rate of 10Hz
Task t1S    (TASK_SECOND, TASK_FOREVER, &t1SCallback);
Task t10S   (10 * TASK_SECOND, TASK_FOREVER, &t10SCallback);
Task t60S   (TASK_MINUTE, TASK_FOREVER, &t60SCallback);
Task t600S  (10 * TASK_MINUTE, TASK_FOREVER, &t600SCallback);
Task t3600S (TASK_HOUR, TASK_FOREVER, &t3600SCallback);

Scheduler runner;

// *********** This is for the serial data parsing ******************
// Create a class for the serial data to be parsed
check_data   checkData;

// *********** This is for the data holders *************************
// Want to create a data class for each channel, up to max of NUM_CHANNELS
data_channel solar_data;    // This creates our data channels


// *********** These are global variables ***************************
String        inputString = "";           // a String to hold incoming data
String        errorString = "";           // a String to hold incoming data
String        returnString = "";          // A string to hold the returned data
bool          stringComplete = false;     // Checks if the string is complete
byte          UNIT_ID = B00000000;        // This is the unit_id of the board itself. This will be default value. Values from 0-255 can potentially be used. 4 bit binary number? = 16 channels.

uint32_t      led_flash_timer = millis();
bool          led_update_flag = true;
uint8_t       led_flash_counter = 0;        // Number of flashes to do
int           vane_training_direction = 0;    // This is used for the vane training mode

volatile int  data_counter_1s = 0;
volatile int  data_counter_10s = 0;
volatile int  data_counter_60s = 0;
volatile int  data_counter_600s = 0;
volatile int  data_counter_3600s = 0;
long int      debounce_time = millis();

void t1Callback() {
  // This loop runs every 100mS
  // This will record the value and store it

  // Check the sensor data
  long dataValue = 0;
  MCP342x::Config status;
  // Initiate a conversion; convertAndRead() will wait until it can be read
  uint8_t err = adc.convertAndRead(MCP342x::channel1, MCP342x::oneShot,
                                   MCP342x::resolution16, MCP342x::gain1,
                                   1000000, dataValue, status);
  if (err)
  {
    // If there is an ADC error, highlight it and dont read the data into the unit
    Serial.print(F("MCP ERR:"));
    Serial.println(err);
  }
  else
  {
    // Otherwise store data and increment data counter
    solar_data.data_1s_holder += dataValue;
    // It will then be averaged for 1s, 10s, 60s 10min and 1 hour averages
    data_counter_1s++;   // This counts the correct number of samples we take within the 1S sample period. Used for averaging.
  }
}
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
void loop()
{
  // Deal with schedules tasks
  runner.execute();
  // Check buttons for input
  buttonA.loop();
  // This flashes the LEDs as needed...
  flashLED();
  // feed the WDT
  wdt_reset();

  // Check for serial data
  if (stringComplete == true)
  {
    // This means we have had some data come in:
    // So parse it to find id and ave
    errorString = checkData.parseData(inputString, UNIT_ID, solar_data);

    if (checkData.error_flag == true)
    {
      if (ADD_CRC_CHECK)
      {
        // Add the CRC here: This adds the ? the CRC and the # to the end
        errorString = add_CRC(errorString);
      }
      else
      {
        errorString += "#";
      }
      if (DEBUG_FLAG == true)
      {
        Serial.println(errorString);    // This needs to be returned only in debug mode!
      }
      checkData.error_flag = false;
    }
    else
    {
      if (checkData.baud_return_flag == true)
      {
        // Here we return the baud rate
        returnString = "aaI";
        returnString += (String)UNIT_ID;
        returnString += "BD";
        returnString += baud_rates[SERIAL_BAUD];
        //returnString += END_STR;
        checkData.baud_return_flag = false;
        checkData.data_sent_flag = false;
      }
      else if (checkData.id_return_flag == true)
      {
        // Return the ID of the unit
        returnString = "aaI";
        returnString += (String)UNIT_ID;
        //returnString += "#";
        checkData.id_return_flag = false;
        checkData.data_sent_flag = false;
      }
      else if (checkData.conversion_return_flag == true)
      {
        // Return conversion settings "aaI0STSSCONm123.4c567.89#"
        returnString = START_STR;
        returnString += (String)UNIT_ID;
        returnString += "SSCONm";
        returnString += (String)solar_data.solar_conv_m;
        returnString += "c";
        returnString += (String)solar_data.solar_conv_c;
        //returnString += END_STR;
        checkData.conversion_return_flag = false;
        checkData.data_sent_flag = false;
      }
      else if (checkData.conversion_set_flag == true)
      {
        // Return conversion settings "aaI0STWSCONm123.4c567.89#"
        solar_data.solar_conv_m = checkData.solar_conv_m;
        solar_data.solar_conv_c = checkData.solar_conv_c;
        // Store this data to EEPROM
        EEPROM.put(CONV_M_EEPROM_LOC, solar_data.solar_conv_m);
        EEPROM.put(CONV_C_EEPROM_LOC, solar_data.solar_conv_c);
        returnString = START_STR;
        returnString += (String)UNIT_ID;
        returnString += "SSSETm";
        returnString += (String)solar_data.solar_conv_m;
        returnString += "c";
        returnString += (String)solar_data.solar_conv_c;
        //returnString += END_STR;
        checkData.conversion_set_flag = false;
        checkData.data_sent_flag = false;
      }
      else if (checkData.temp_con_status_flag == true)
      {
        solar_data.solar_tempcon_flag = checkData.solar_tempcon_flag;
        // store the new data to EEPROM:
        EEPROM.put(TEMP_COMP_FLAG_LOC, solar_data.solar_tempcon_flag); 
        returnString = START_STR;
        returnString += (String)UNIT_ID;
        if(solar_data.solar_tempcon_flag == true)
        {
          returnString += "SSTCONON";
        }
        else
        {
          returnString += "SSTCONOFF";
        }
        checkData.temp_con_status_flag = false;
        checkData.data_sent_flag = false;
      }
      else if (checkData.temp_con_set_flag == true)
      {
        // Return temperature conversion settings "aaI0SSTCONp0.18r25.0#"
        solar_data.solar_tempcon_percentage = checkData.solar_tempcon_percentage;
        solar_data.solar_tempcon_rated_c = checkData.solar_tempcon_rated_c;
        // Store this data to EEPROM
        EEPROM.put(TEMP_COMP_PERCENTAGE_LOC, solar_data.solar_tempcon_percentage);
        EEPROM.put(TEMP_COMP_RATED_C_LOC, solar_data.solar_tempcon_rated_c);
        returnString = START_STR;
        returnString += (String)UNIT_ID;
        returnString += "SSTCONp";
        returnString += (String)solar_data.solar_tempcon_percentage;
        returnString += "r";
        returnString += (String)solar_data.solar_tempcon_rated_c;
        checkData.temp_con_set_flag = false;
        checkData.data_sent_flag = false;
      }
      else if (checkData.temp_con_return_flag == true)
      {
        // Return temperature conversion settings "aaI0SSTCONp0.18r25.0#"
        returnString = START_STR;
        returnString += (String)UNIT_ID;
        returnString += "SSTCONp";
        returnString += (String)solar_data.solar_tempcon_percentage;
        returnString += "r";
        returnString += (String)solar_data.solar_tempcon_rated_c;
        checkData.temp_con_return_flag = false;
        checkData.data_sent_flag = false;
      }
      else if (checkData.baud_set_flag == true)
      {

        Serial.end();  // STOP the serial and restart at new baud rate
        // Here we set the baud rate to a new value and store in EEPROM
        returnString = START_STR;
        returnString += (String)UNIT_ID;
        returnString += "STBD";
        // Read the serial baud rate set in EEPROM
        SERIAL_BAUD = EEPROM.read(BAUD_RATE_EEPROM_LOC);
        if (SERIAL_BAUD >= MAX_BAUD_RATES)
        {
          SERIAL_BAUD = 2;  // Initialise to 9600 if data out of range
        }
        // re-initialize serial communication:
        Serial.begin(baud_rates[SERIAL_BAUD]);
        returnString += baud_rates[SERIAL_BAUD];
        checkData.baud_set_flag = false;
        checkData.data_sent_flag = false;
      }
      else if (checkData.data_sent_flag == true)
      {
        if (checkData.data_all_flag == true)
        {
          //******** RETURN ALL DATA FOR AVE *************************
          DEBUGLN(DEBUG_FLAG, "Return ALL DATA");
          sendData(checkData.ave_time, false);
          checkData.data_all_flag = false;
          checkData.data_sent_flag = false;
        }
        else if (checkData.data_min_flag == true)
        {
          //******** RETURN ALL MINIMUMS *************************
          DEBUGLN(DEBUG_FLAG, "Return ALL MINIMUMS");
          returnString = START_STR;
          returnString += (String)UNIT_ID;
          returnString += "SSMN"; // Initialise the returned string
          returnString += ":";
          returnString += (String)solar_data.data_min;
          checkData.data_min_flag = false;
          checkData.data_sent_flag = false;
        }
        else if (checkData.data_max_flag == true)
        {
          //******** RETURN ALL MAXIMUMS  *************************
          DEBUGLN(DEBUG_FLAG, "Return ALL MAXIMUMS");
          returnString = START_STR;
          returnString += (String)UNIT_ID;
          returnString += "SSMX"; // Initialise the returned string
          returnString += ":";
          returnString += (String)solar_data.data_max;
          checkData.data_max_flag = false;
          checkData.data_sent_flag = false;
        }
      }
      else if (checkData.data_reset_flag == true)
      {
        // Want to reset the wind vane direction data as previous will be wrong!
        reset_data();
        returnString = F("aaRESET");   // This needs to be returned
        checkData.data_reset_flag = false;
        checkData.data_sent_flag = false;
      }
      else if (checkData.send_data_flag == true)
      {
        // In this case we start to send data at regular intervals.
        solar_data.send_solar_data = EEPROM.read(SEND_ID_EEPROM_LOC);
        if (solar_data.send_solar_data < 5)
        {
          returnString = F("aaSENDON");
        }
        else
        {
          returnString = F("aaSENDOFF");
        }
        checkData.send_data_flag = false;
        checkData.data_sent_flag = false;
      }
      else
      {
        // Do not want anything sent back here when connected to logger:
        if (DEBUG_FLAG == true)
        {
          returnString = F("aaFAILCRC");
        }
        checkData.data_sent_flag = false;
      }
      if (checkData.button_press_flag == true)
      {
        tap(buttonA);
      }
      else
      {
        if (ADD_CRC_CHECK)
        {
          // Add the CRC here: This adds the ? the CRC and the # to the end
          returnString = add_CRC(returnString);
        }
        else
        {
          returnString += END_STR;
        }

        DEBUGLN(DEBUG_FLAG, "Returned string:");
        if (returnString != FAIL_STR)
        {
          Serial.println(returnString);
        }
      }
    }
    inputString = "";
    stringComplete = false;
  }
}
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

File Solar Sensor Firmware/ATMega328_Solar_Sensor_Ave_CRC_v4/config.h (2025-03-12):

#pragma once

#include <Arduino.h>
#include <Wire.h>

#define LED0_PIN          7 
#define SWA_PIN           8
#define ANALOG_OUT_PIN    6

#define LED_FLASH_TIME    5000  // time in mS between LED flashes
#define LED_ON_TIME       50   // time in mS of the flash length

#define HC12_PWR_PIN      9     // This is a power output for the HC12 unit - set to D9 at present. Not yet implemented.
#define POWER_SETTLE_TIME 0     // Time in mS to wait after power is applied before sending serial data and time to wait after data set before switching off power.

//// The baud rate for serial communications
#define MAX_BAUD_RATES            5
#define BAUD_RATE_EEPROM_LOC      10    // EEPROM location for baud rate save
#define CONV_M_EEPROM_LOC         100      // EEPROM location for  save
#define CONV_C_EEPROM_LOC         110      // EEPROM location for  save
#define SEND_ID_EEPROM_LOC        120      // EEPROM location for  save
#define TEMP_COMP_FLAG_LOC        130
#define TEMP_COMP_RATED_C_LOC     132
#define TEMP_COMP_PERCENTAGE_LOC  140

#define APPLY_TEMP_COMP_INIT   true  // Do you want the irradiance compensated for temperature?
#define TEMP_COMP_VAL_INIT     0.18  // % change in short circuit current away from rated temperature
#define RATED_TEMP_INIT        25.0  // Datasheet value about temperature rating

#define ADD_CRC_CHECK     false    // Use this to add CRC check to incomming and outgoing messages

#define DEBUG_FLAG        false   // Use this for debugging. Not need for roll out.
#define DEBUG_DATA_1S     false   // Use this for debugging. Not need for roll out.
#define DEBUG_DATA_10S    false   // Use this for debugging. Not need for roll out.
#define DEBUG_DATA_60S    false   // Use this for debugging. Not need for roll out.
#define DEBUG_DATA_600S   false   // Use this for debugging. Not need for roll out.
#define DEBUG_DATA_3600S  false   // Use this for debugging. Not need for roll out. 
                           
#define DEBOUNCE_DELAY    5       // debounce delay time in milli-Seconds This also gives max pulses - 5mS = 200 pulses per second                                   
                            
// These three digital pins are for the Device ID selection:
#define  GPIO_ID0      A0  //  A0 Digital 4 on Arduino
#define  GPIO_ID1      A1  //  A1 Digital 5 on Arduino
#define  GPIO_ID2      A2  //  A3 Digital 6 on Arduino

// I2C ADC is on standard I2C Pins: A4 (SDA) and A5 (SCL)

#define FAIL_STR              "aaFAIL"
#define START_STR             "aaI"
#define END_STR               "#"

#define MCP_ADDRESS           0x68

#define M_CONV_INIT           10.0    // Initialisation value is EEPROM not previously set
#define C_CONV_INIT           0.0     // Initialisation value is EEPROM not previously set

#define MAX_IRRADIANCE        2000    // This is the value for the PWM output being Vcc. So 1000W/m2 is Vcc/2

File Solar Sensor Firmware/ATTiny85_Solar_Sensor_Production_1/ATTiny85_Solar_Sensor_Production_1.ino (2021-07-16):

/*
   Solar Sensor firmware for ATTin85
   by:    Matt Little
   date:  20/6/2021
   w:     www.curiouselectric.co.uk
   e:     hello@curiouselectric.co.uk

   This code is for an ATTiny85 unit solar sensor unit.
   More construction details are here:
   https://github.com/curiouselectric/SolarSensor
   and
   *** link to web page for design documentation ***

   This unit serives serial port requests at 9600 baud.
   It measures irradiance from a photodiode sensor with an amplifier and then by an I2C ADC (ADS1115)
   It measure temperature via an I2C temperature sensor (LM75B)
   There is a push switch and LED for human interfacing.
   Floats have been removed as they take up >1k memory...

   It can be set to either:
   Respond to serial data requests or constantly (at 1s, 10s and 1min times) output data.
   Typically responding to serial data requests is best!
   Data supplied is the average irradiance level and the average temperature of the sensor.
   At other times it sleeps, to ensure low power consumption.

   Serial data requests:

   Change ID
   "aAACHIDBB#"
   Will change the ID from AA to BB.
   Will return "aBBOK#" if OK or "aAAFAIL#" if not changed
   "a**CHID&&#"
   Will just return the units ID

   Request data "aAARQ#"
   will return: "aAAI****T***#" or "aAAFAIL#"
   Where AA is the device ID


   ATTiny85 Upload Data

   Fuses required:
   Extended:  0xFF
   High:      0xD6
   Low:       0x62

   TO DO:
   Sort out return data on serial command
   Sort out Stored ID and changing ID


*/
#define F_CPU 8000000  // This is used by delay.h library

#include <stdlib.h>
#include <EEPROM.h>
#include <Arduino.h>
#include <avr/sleep.h>

// Routines to set and clear bits (used in the sleep code)
#ifndef cbi
#define cbi(sfr, bit) (_SFR_BYTE(sfr) &= ~_BV(bit))
#endif
#ifndef sbi
#define sbi(sfr, bit) (_SFR_BYTE(sfr) |= _BV(bit))
#endif

#include <SoftwareSerial.h>
#include <TinyWireM.h>                  // I2C Master lib for ATTinys which use USI
#include <Adafruit_ADS1X15.h>
#include <Temperature_LM75_Derived.h>

// ****** ATTiny85 Pin Definitions: ************** //
#define pinI2C_SDA    PB0  // convert to arduino digital pins
#define pinSW1        PB1
#define pinI2C_CLK    PB2
#define pinRx         PB3  // wake on interrupt here...  
#define pinTx         PB4
// *********************************************** //

SoftwareSerial mySerial(pinRx, pinTx); //rx, tx

Adafruit_ADS1115 ads;  /* Use this for the 16-bit version */
//Adafruit_ADS1015 ads;     /* Use this for the 12-bit version */

// The Generic_LM75 class will provide 9-bit (±0.5°C) temperature for any
// LM75-derived sensor. More specific classes may provide better resolution.
Generic_LM75 temperature;

// ********* USER VARIABLES *************************************
uint8_t samples = 8;   // Number of 0.25S samples to use for the data averaging

// ******* PROGRAM VARIABLES *************************************

uint32_t  dataAveTemp = 0;
uint32_t  dataAve = 0;        // Holds the average sensor readings
uint16_t  dataTemperature = 0;
uint8_t   dataCounter = 0;
uint32_t  dataWm2 = 0;            // Holds the converted W/m2 data

// This holds the calibration vlaues to perform y=mx+c conversion.
// Data in Irradiance (W/m2) is converter from sensor readings using y=mx+c
// You can enter c by covering totally and requesting the dark calibration
// You can write m by applying a known irradiance and requesting the light calibration

uint16_t  dataMIrradiance;
uint16_t  dataMSensor;
int       hiByte;      // These are used to store longer variables into EERPRPROM
int       loByte;

boolean show_data_flag = false;

// *********** This is for the serial data parsing ***************
char    inChar;         // incoming serial byte
String  str_buffer = "";         // a String to hold incoming data
String  outputString = "";         // a String to hold outgoing data
char    startChar = 'a';
char    endChar = '#';
char    tempChar = 'T';
char    irrChar = 'I';


// Variables for the Sleep/power down modes:
volatile boolean f_wdt = 1;

// Useful variables
char deviceID[2]; // A buffer to hold the device ID

void setup()
{
  // Read in the values from EEPROM
  // Read the device ID
  deviceID[0] = char(EEPROM.read(0));
  deviceID[1] = char(EEPROM.read(1));

  mySerial.begin(9600);

  TinyWireM.begin();                    // initialize I2C lib

  // ADC setup
  // The ADC input range (or gain) can be changed via the following
  // functions, but be careful never to exceed VDD +0.3V max, or to
  // exceed the upper and lower limits if you adjust the input range!
  // Setting these values incorrectly may destroy your ADC!
  //                                                                ADS1015  ADS1115
  //                                                                -------  -------
  // ads.setGain(GAIN_TWOTHIRDS);  // 2/3x gain +/- 6.144V  1 bit = 3mV      0.1875mV (default)
  ads.setGain(GAIN_ONE);        // 1x gain   +/- 4.096V  1 bit = 2mV      0.125mV
  // ads.setGain(GAIN_TWO);        // 2x gain   +/- 2.048V  1 bit = 1mV      0.0625mV
  // ads.setGain(GAIN_FOUR);       // 4x gain   +/- 1.024V  1 bit = 0.5mV    0.03125mV
  // ads.setGain(GAIN_EIGHT);      // 8x gain   +/- 0.512V  1 bit = 0.25mV   0.015625mV
  // ads.setGain(GAIN_SIXTEEN);    // 16x gain  +/- 0.256V  1 bit = 0.125mV  0.0078125mV
  ads.begin();

  // Resevres some memory for the string buffer
  str_buffer.reserve(10);
  outputString.reserve(15);

  // Watch dog timer setup
  setup_watchdog(4);      // approximately 0.064 seconds sleep between reads for averaging
  // 0=16ms, 1=32ms,2=64ms,3=128ms,4=250ms,5=500ms
  // 6=1 sec,7=2 sec, 8=4 sec, 9= 8sec
}
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

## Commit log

2017-06-11 Initial commit of files
    [SolarSensorPCB.kicad_pcb, SolarSensorPCB.sch]
2021-06-20 Large update of firmware and PCB
    [SolarSensorPCB-2021-06-18-14-28-08.sch, SolarSensorPCB.kicad_pcb]
2021-06-20 Updated PCB. Not finished yet!
    [SolarSensorPCB.kicad_pcb, SolarSensorPCB.sch]
2021-07-04 Updated PCB v0.1
    [BOM_UPLOAD_PCB.csv, SolarSensorPCB.kicad_pcb, SolarSensorPCB.sch]
2021-07-16 Updated firmware. Updated PCB
    [SolarSensorPCB.kicad_pcb, SolarSensorPCB.sch]
2021-07-19 big update of PCB
    Changed from ATTiny85 to ATmega328
    [BOM_SOLAR_SENSOR_PCB.csv, BOM_UPLOAD_PCB.csv, LM75TempSensor.sch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]
2021-10-29 large update of firmware & PCB changes
    This version works
    [BOM_SOLAR_SENSOR_PCB.csv, PhotoDiodeSensorMCP3426.sch, SolarSensorATMEGA328_PCB.kicad_pcb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]
2021-11-28 Updated diffuser design
    [Diffuser_Stepped_design_6mm_PTFE.FCStd, Diffuser_Stepped_design_v2_6mm_PTFE-Fusion.stl, Diffuser_Stepped_design_v2_6mm_PTFE.FCStd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]
2021-12-05 Updated diffuser model
    [Diffuser_Stepped_design_v2_6mm_PTFE-Fusion.stl, Diffuser_Stepped_design_v2_6mm_PTFE.FCStd, Diffuser_Stepped_design_v3_6mm_PTFE-Fusion.stl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]
2021-12-05 PCB update small
    [SolarSensorATMEGA328_PCB.kicad_pcb]
2021-12-17 updated new PCB version
    [SolarSensorATMEGA328_PCB.kicad_pcb, SolarSensorATMEGA328_PCB.sch]
2022-01-01 Updated PCB and Firmware
    Added 3D models to new Kicad PCB
    [PhotoDiodeSensorMCP3426.sch, SolarSensorATMEGA328_PCB.kicad_pcb, SolarSensorATMEGA328_PCB.sch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]
2022-04-05 Updated firmware.
    Sorted serial requests
    [BOM_SolarSensorATMEGA328_PCB_JLCPCB.csv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]
2022-04-14 Updated Firmware. Updated Mounting design
    Firmware not fully complete - still needs temperature compensation.
2022-04-14 Firmware update- added temperature compensation
2025-03-10 Large update
    Add CRC to firmware
    Update readme
    Update PCB to kicad 9
    [LM75TempSensor.kicad_sch, PhotoDiodeSensorMCP3426.kicad_sch, SolarSensorATMEGA328_PCB.kicad_pcb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]
2025-03-12 updated with temperature compensation updating
